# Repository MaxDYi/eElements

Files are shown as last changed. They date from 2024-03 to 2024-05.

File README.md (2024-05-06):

# 墨水屏元素周期表

# 0 目录

1. 简介
2. 原理图
3. PCB
4. 外壳
5. 物料清单
6. 成本核算
7. 代码实现
8. 功耗分析

# 1 简介

电子沙漏使用STM32L431CCT6作为主控，驱动1.54寸墨水屏（200x200分辨率），待机功耗低。

- 原子序数、原子序数、相对原子量、核外电子排布以及中英文原子名称。
- 整机刷新功耗5mA，休眠功耗136uA，续航达数月。

# 2 原理图

eElements-SCH_page-0001

# 3 PCB





PCB使用4层板设计，面积3.2x4.0cm，全部元器件均位于背面。

# 4 外壳

外壳设计详见github库中的**4.Component**部分，共设计**内层**与**外层**两部分，使用3D打印进行实现。

| 元件 | 尺寸 |  体积 |  表面积  |
| :--: | :---: | :-----: | :---: |
| 内层 | 1.17 * 3.2 * 4.24cm | 2.49cm³ | 39.59cm² |
| 外层 | 1.37 * 3.5 * 4.34cm | 3.57cm³ | 73.94cm² |

# 5 物料清单

| Comment | Description | Designator | Footprint | Quantity |
| --- | --- | --- | --- | --- |
| 100nF | 贴片电容/MLCC电容 | C2, C4, C5, C6, C7,  C8, C21, C22, C26, C27 | C0402_M | 10 |
| 1uF/50V | 贴片电容/MLCC电容 | C9, C10, C11, C12,  C13, C14, C15, C16, C17, C18 | C0402_M | 10 |
| 10uF | 贴片电容/MLCC电容 | C19, C20 | C0402_M | 2 |
| 1uF | 贴片电容/MLCC电容 | C23, C24 | C0402_M | 2 |
| 22nF | 贴片电容/MLCC电容 | C25 | C0402_M | 1 |
| 1N5819WS | 肖特基二极管 | D1, D2, D3, D4, D5,  D6, D7 | SOD-323 | 7 |
| DEBUG PAD | 调试断点焊盘 | DE1 | DEBUG_B | 1 |
| TP4056 | 锂电池充电管理 | IC1 | SOIC-8_EP | 1 |
| CON-24P | 2.54寸墨水屏24P连接器 | JP1 | FPC0.5-WT-24P-上接 | 1 |
| HDR-1X2 | 2P连接器 | JP2 | MX1.25-W-2P | 1 |
| HDR-1X4 | 4P连接器 | JP3 | HDR1.27-LI-4P | 1 |
| 47uH/1A | 贴片小功率电感 | L1 | SWPA4030 | 1 |
| GREEN | 贴片LED | LED1, LED3 | LED0603_R | 2 |
| RED | 贴片LED | LED2 | LED0603_R | 1 |
| AO3400 | N沟道 30V/4.2A | Q1, Q3 | SOT23-3N | 2 |
| AO3401 | P沟道 30V/4.2A | Q2 | SOT23-3N | 1 |
| 1K | 贴片电阻 | R1, R7, R8 | R0402_M | 3 |
| 100K | 贴片电阻 | R2, R16 | R0402_M | 2 |
| 4.7K | 贴片电阻 | R3, R4 | R0402_M | 2 |
| 1M | 贴片电阻 | R5, R13, R14, R15,  R19 | R0402_M | 5 |
| 2.2R | 贴片电阻 | R6 | R0603_M | 1 |
| 10K | 贴片电阻 | R9, R12, R17, R18 | R0402_M | 4 |
| 5.1K | 贴片电阻 | R10, R11 | R0402_M | 2 |
| 3x6x5 | 微动开关 | SW1 | SW 3*6*4.3-S-W | 1 |
| 3x6x5 | 微动开关 | SW2, SW3 | SW SMD-3*6*2.5 | 2 |
| STM32L431CCT6 | Ultra-low-power with  FPU Arm Cortex-M4 MCU | U1 | LQFP48_M | 1 |
| RT9193-33GB | LDO 3.3V/0.3A | U2 | SOT-23-5 | 1 |
| CH340K | USB转串口芯片, 内置晶振 | U3 | SOP10_M | 1 |
| TYPE-C 2.0  -16P | USB2.0_Type-C_16Pin母座 | USBC1 | USB-C-SMD_16P | 1 |

# 6 成本核算

|  类目  | 型号 | 采购总价 | 采购数量 | 采购单价 | 使用数量 |  小计  |
| :----: | :---: | :---: | :---: | :---: | :---: | :----: |
|  PCB | 四层板1.6mm |  ¥20.00  | 5 | ¥4.0000  | 1 | ¥4.00  |
|  SMT | 经济型 | ¥100.06  | 5 | ¥20.0120 | 1 | ¥20.01 |
| 元器件 | STM32L431CCT6等  |  ¥7.20 | 1 | ¥7.2000  | 1 | ¥7.20  |
|  外壳  | 外壳（白色树脂） |  ¥4.96 | 1 | ¥4.9600  | 1 | ¥4.96  |
| 锂电池 | 500mAh单节锂电池 |  ¥8.20 | 1 | ¥8.2000  | 1 | ¥8.20  |
|  合计  | | | | | | ¥65.92 |

# 7 代码实现

## 7.1 软件环境

IAR 9.30

STM32CubeMX 6.5.0

## 7.2 主要库

使用到的库位于**\eHorglass\Drivers**路径下。

| 库 | 功能 |
| --- | --- |
| battery | 锂电池相关库 |
| bsp | 开发板相关 |
| element | 元素信息存储 |
| epd | 墨水屏驱动库 |
| parameter | 运行参数配置库 |
| PWRSandMove | 电源与低功耗控制砂砾运动控制核心算法 |

# 8 功耗分析

使用Power Profiler Kit II进行功耗分析。



固件采取刷新后休眠30s的运行模式，对功耗进行测量。

| 模式 | 功耗 | 时长 |
| :---: | :---: | :--: |
| 关机功耗 | 30.95uA  |  0s  |
| 刷新功耗 |  5.09mA  |  2s  |
| 休眠功耗 | 136.13uA | 10s  |

ppk-20240401T023107

ppk-20240401T023441

ppk-20240401T044010

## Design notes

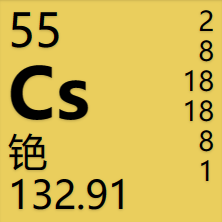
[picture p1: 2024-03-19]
6.Docs/参考排版/元素图例（无边框）.png

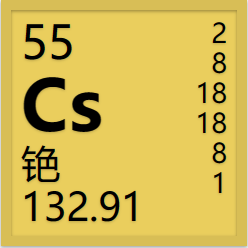
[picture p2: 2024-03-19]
6.Docs/参考排版/元素图例.png

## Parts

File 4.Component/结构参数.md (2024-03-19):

屏幕 37.32x31.8x0.98mm

PCB 40.0x32.0x1.6mm

外壳厚度1.2mm

器件高度4.0mm

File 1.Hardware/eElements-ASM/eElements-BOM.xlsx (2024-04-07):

Comment | Description | Designator | Footprint | LibRef | Quantity
100nF | 贴片电容/MLCC电容 | C2, C4, C5, C6, C7, C8, C21, C22, C26, C27 | C0402_M | C | 10
1uF/50V | 贴片电容/MLCC电容 | C9, C10, C11, C12, C13, C14, C15, C16, C17, C18 | C0402_M | C | 10
10uF | 贴片电容/MLCC电容 | C19, C20 | C0402_M | C | 2
1uF | 贴片电容/MLCC电容 | C23, C24 | C0402_M | C | 2
22nF | 贴片电容/MLCC电容 | C25 | C0402_M | C | 1
1N5819WS | 肖特基二极管 | D1, D2, D3, D4, D5, D6, D7 | SOD-323 | 1N5819 | 7
DEBUG PAD | 调试断点焊盘 | DE1 | DEBUG_B | DEBUG | 1
TP4056 | 锂电池充电管理 | IC1 | SOIC-8_EP | TP4056 | 1
CON-24P | 2.54寸墨水屏24P连接器（上接点或上下接点24PIN的0.5mmFPC插座） | JP1 | FPC0.5-WT-24P-上接 | EPD-1.54 | 1
HDR-1X2 | 2P连接器 | JP2 | MX1.25-W-2P | Header 2 | 1
HDR-1X4 | 4P连接器 | JP3 | HDR1.27-LI-4P | Header 4 | 1
47uH/1A | 贴片小功率电感 | L1 | SWPA4030 | L | 1
GREEN | 贴片LED | LED1, LED3 | LED0603_R | LED | 2
RED | 贴片LED | LED2 | LED0603_R | LED | 1
AO3400 | N沟道 30V/4.2A | Q1, Q3 | SOT23-3N | AO3400 | 2
AO3401 | P沟道 30V/4.2A | Q2 | SOT23-3N | AO3401 | 1
1K | 贴片电阻 | R1, R7, R8 | R0402_M | R | 3
100K | 贴片电阻 | R2, R16 | R0402_M | R | 2
4.7K | 贴片电阻 | R3, R4 | R0402_M | R | 2
1M | 贴片电阻 | R5, R13, R14, R15, R19 | R0402_M | R | 5
2.2R | 贴片电阻 | R6 | R0603_M | R | 1
10K | 贴片电阻 | R9, R12, R17, R18 | R0402_M | R | 4
5.1K | 贴片电阻 | R10, R11 | R0402_M | R | 2
3x6x5 | 微动开关 | SW1 | SW 3*6*4.3-S-W | SW-PB | 1
3x6x5 | 微动开关 | SW2, SW3 | SW SMD-3*6*2.5 | SW-PB | 2
STM32L431CCT6 | Ultra-low-power with FPU Arm Cortex-M4 MCU 80 MHz with 256 Kbytes of Flash memory | U1 | LQFP48_M | STM32L431CCT6 | 1
RT9193-33GB | LDO 3.3V/0.3A | U2 | SOT-23-5 | RT9193-33GB | 1
CH340K | USB转串口芯片, 内置晶振 | U3 | SOP10_M | CH340K | 1
TYPE-C 2.0 -16P | USB2.0_Type-C_16Pin母座 | USBC1 | USB-C-SMD_16P | USB2.0_Type-C_16Pin | 1

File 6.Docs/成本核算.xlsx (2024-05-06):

类目 | 型号 | 采购总价 | 采购数量 | 采购单价 | 使用数量 | 小计
PCB | 四层板1.6mm | ¥20.00 | 5 | ¥4.0000 | 1 | ¥4.00 | ¥4.00
SMT | 经济型 | ¥100.06 | 5 | ¥20.0120 | 1 | ¥20.01 | ¥20.01
元器件 | STM32L431CCT6 | ¥7.20 | 1 | ¥7.2000 | 1 | ¥7.20
 | 墨水屏 | ¥16.50 | 1 | ¥16.5000 | 1 | ¥16.50
 | CH340K | ¥1.90 | 1 | ¥1.9000 | 1 | ¥1.90
 | TP4056X | ¥1.15 | 1 | ¥1.1500 | 1 | ¥1.15
 | 其他 | ¥10.00 | 5 | ¥2.0000 | 1 | ¥2.00 | ¥28.75
外壳 | 内层 | ¥2.04 | 1 | ¥2.0400 | 1 | ¥2.04
 | 外层 | ¥2.92 | 1 | ¥2.9200 | 1 | ¥2.92
锂电池 | 500mAh单节锂电池 | ¥8.20 | 1 | ¥8.2000 | 1 | ¥8.20
合计 |  |  |  |  |  | ¥65.92

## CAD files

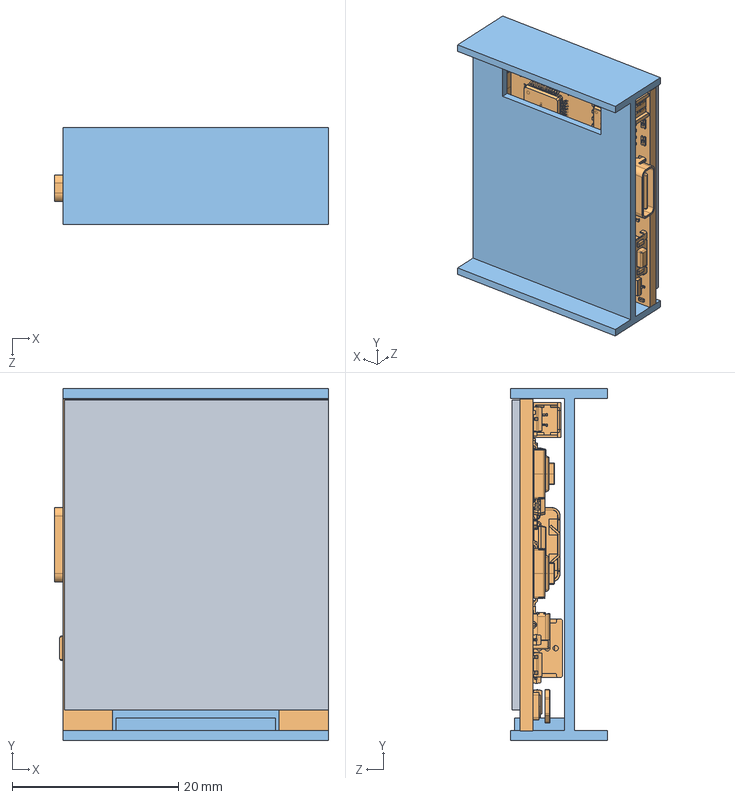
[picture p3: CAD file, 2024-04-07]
4.Component/装配体/内部装配体.SLDASM
33.0 x 42.4 x 11.7 mm
1.54寸电子纸
PCB
内层

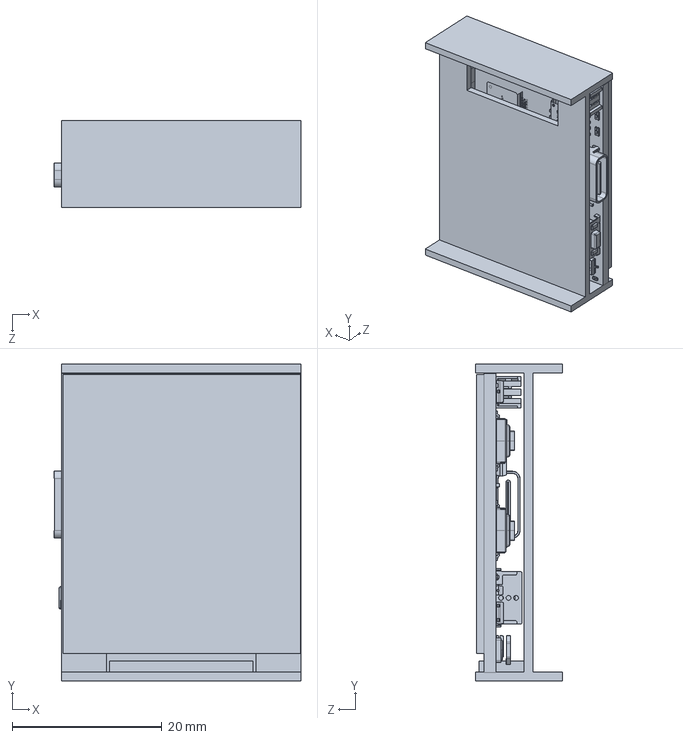
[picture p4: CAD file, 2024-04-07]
4.Component/装配体/整体装配体.SLDASM
33.0 x 42.4 x 11.7 mm

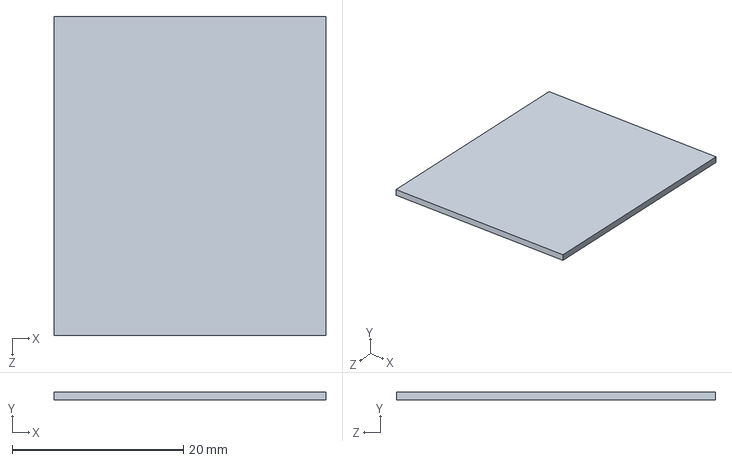
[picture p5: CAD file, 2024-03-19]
4.Component/1.54寸电子纸/1.54寸电子纸.SLDPRT
31.8 x 0.98 x 37.3 mm

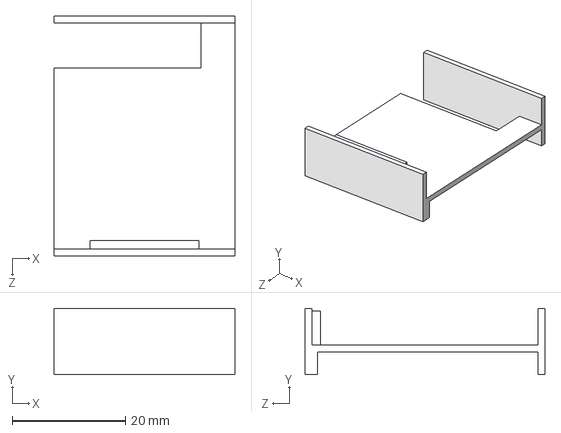
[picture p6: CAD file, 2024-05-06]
4.Component/外壳/内层.STEP
32.0 x 11.7 x 42.4 mm

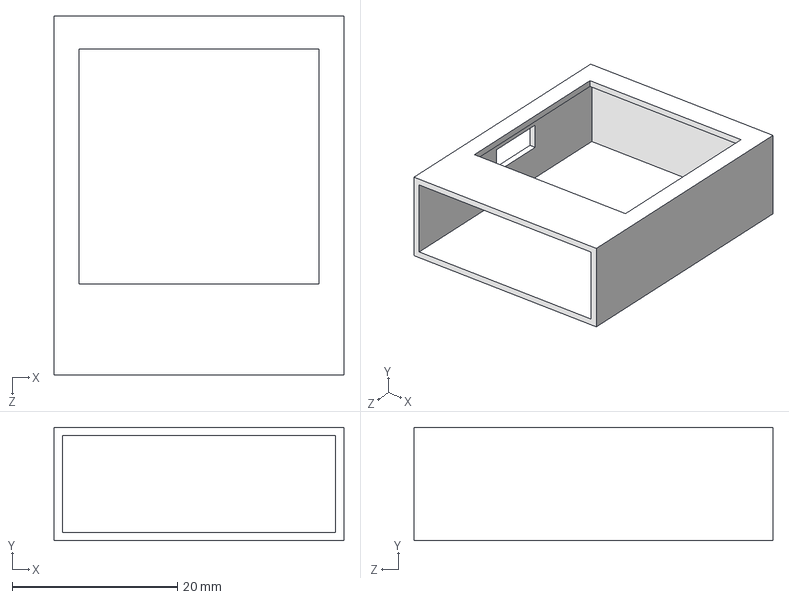
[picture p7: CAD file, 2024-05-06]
4.Component/外壳/外壳.STEP
35.0 x 13.7 x 43.4 mm

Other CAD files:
4.Component/外壳/内层.SLDPRT
4.Component/外壳/外壳.SLDPRT
4.Component/装配体/内部装配体.SLDPRT

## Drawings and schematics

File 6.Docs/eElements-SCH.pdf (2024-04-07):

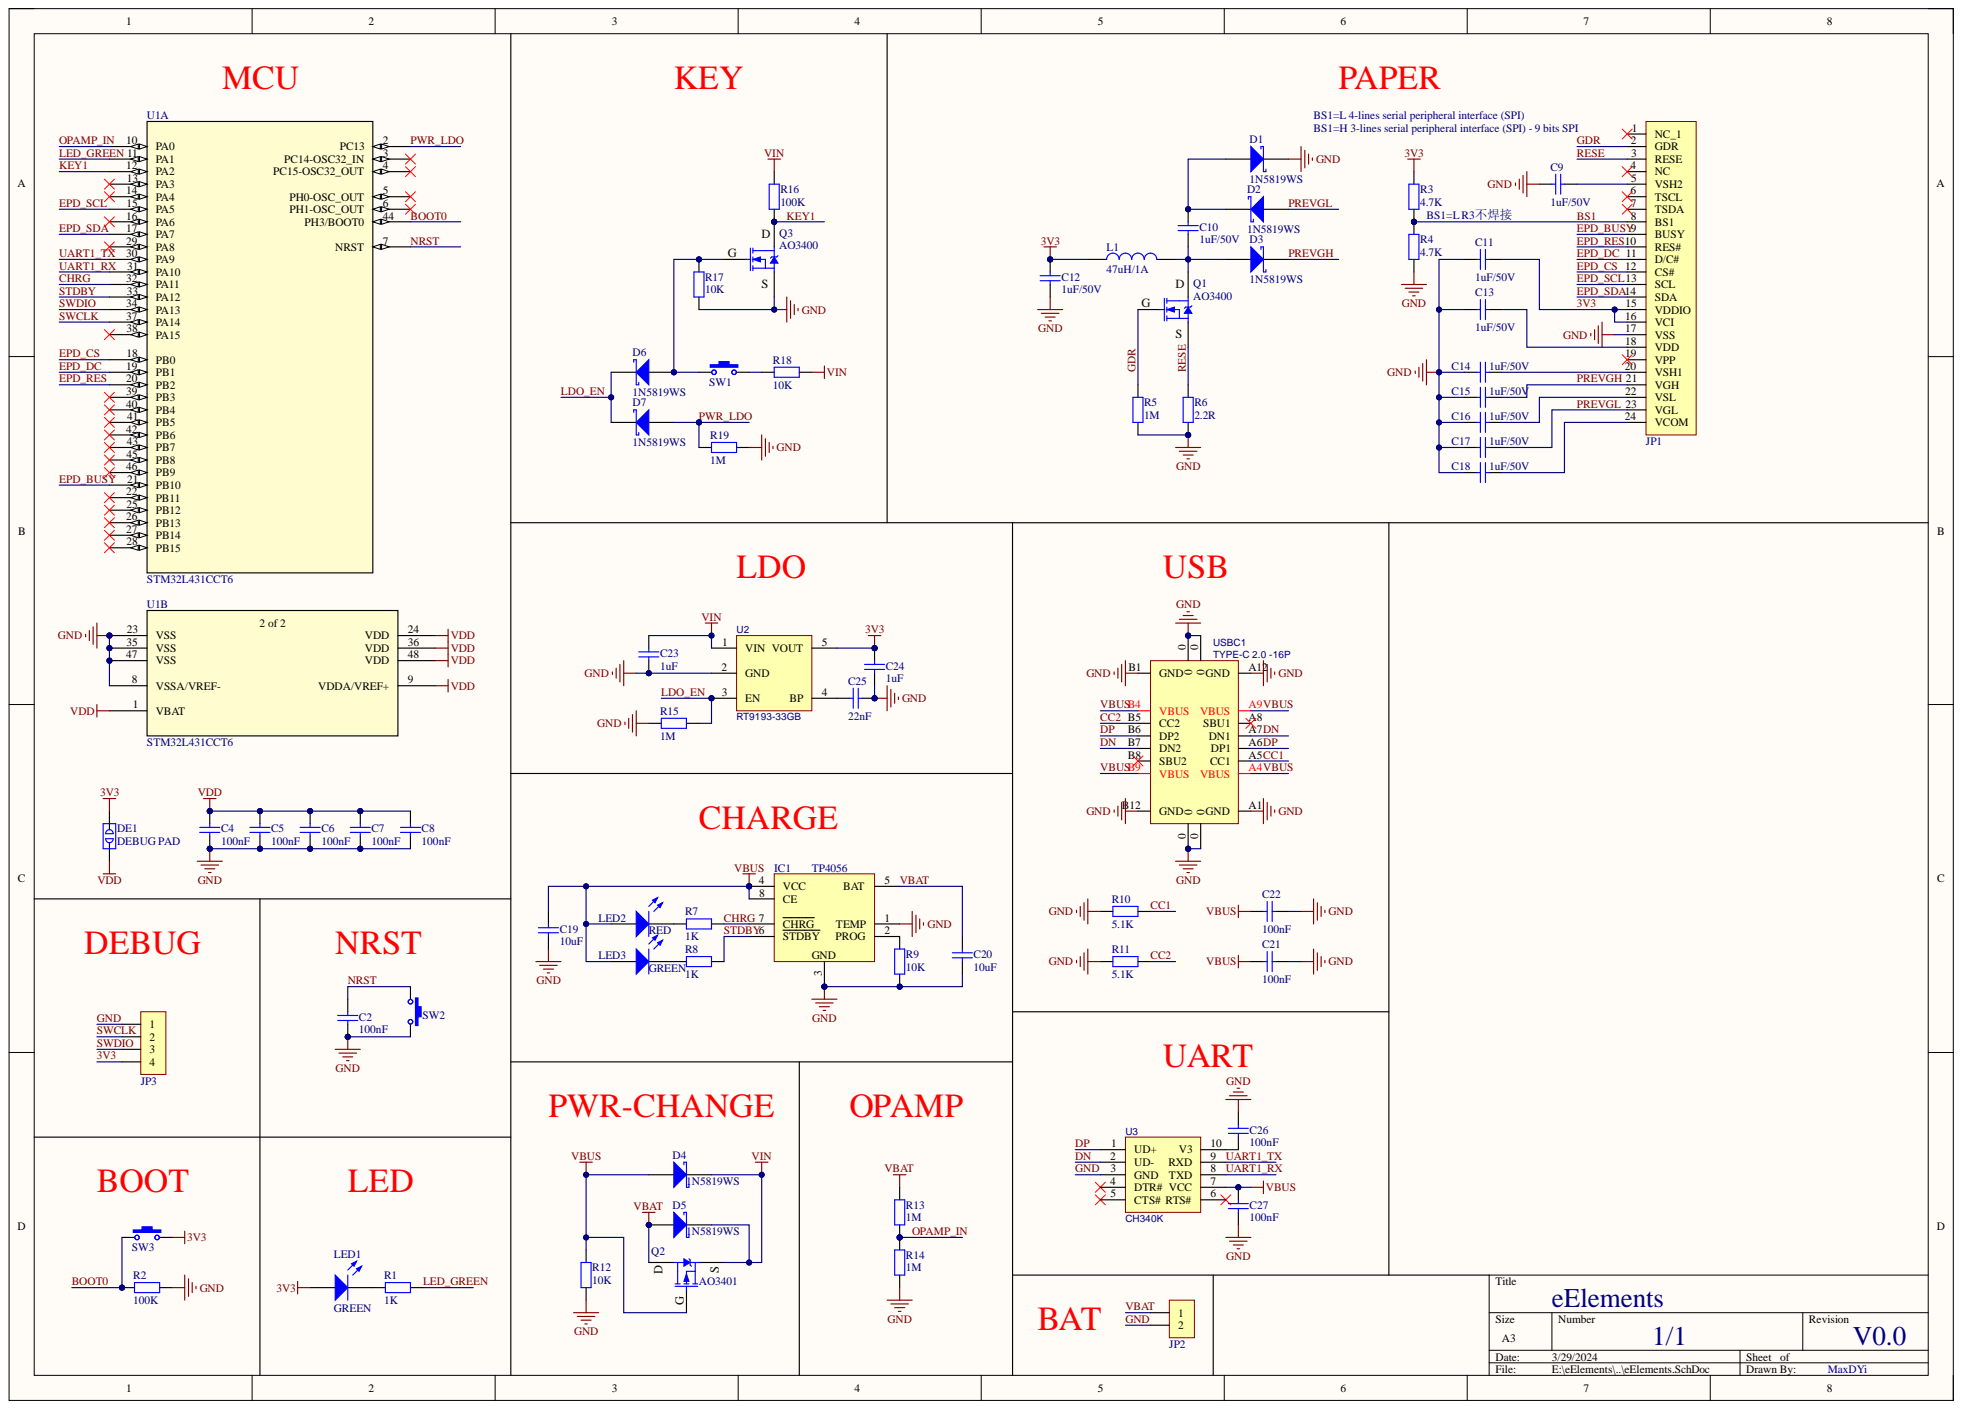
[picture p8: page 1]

BS1=L 4-lines serial peripheral interface (SPI)
BS1=H 3-lines serial peripheral interface (SPI) - 9 bits SPI

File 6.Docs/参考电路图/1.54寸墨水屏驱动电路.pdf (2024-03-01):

接口配置方法： 4线SPI接口焊接：R2 | BS1=L 4-lines serial peripheral interface (SPI)
3线SPI接口焊接：R3 | BS1=H 3-lines serial peripheral interface (SPI) – 9 bits SPI

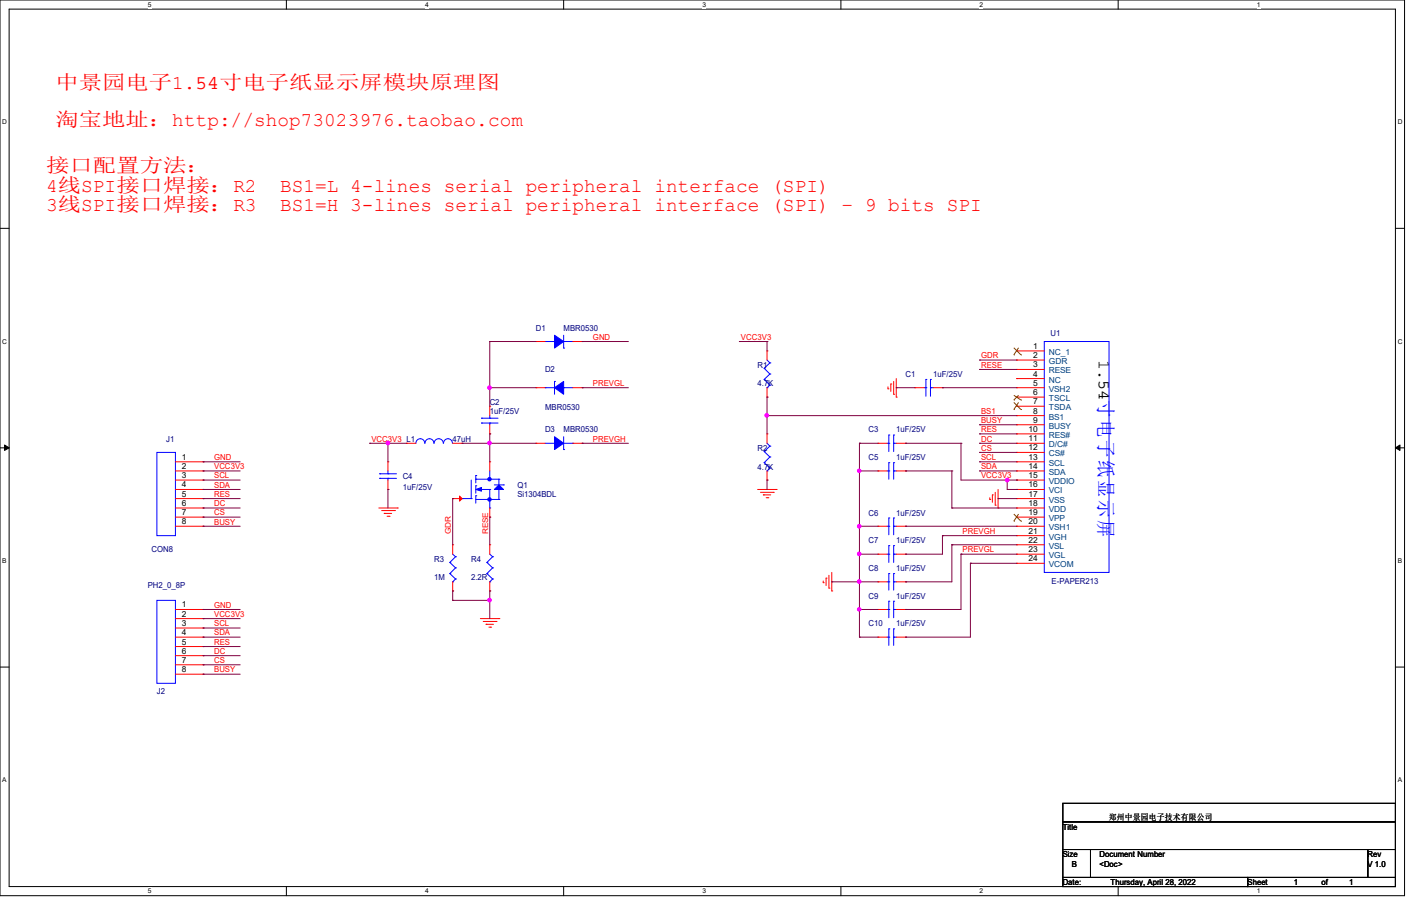
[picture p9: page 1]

淘宝地址：http://shop73023976.taobao.com

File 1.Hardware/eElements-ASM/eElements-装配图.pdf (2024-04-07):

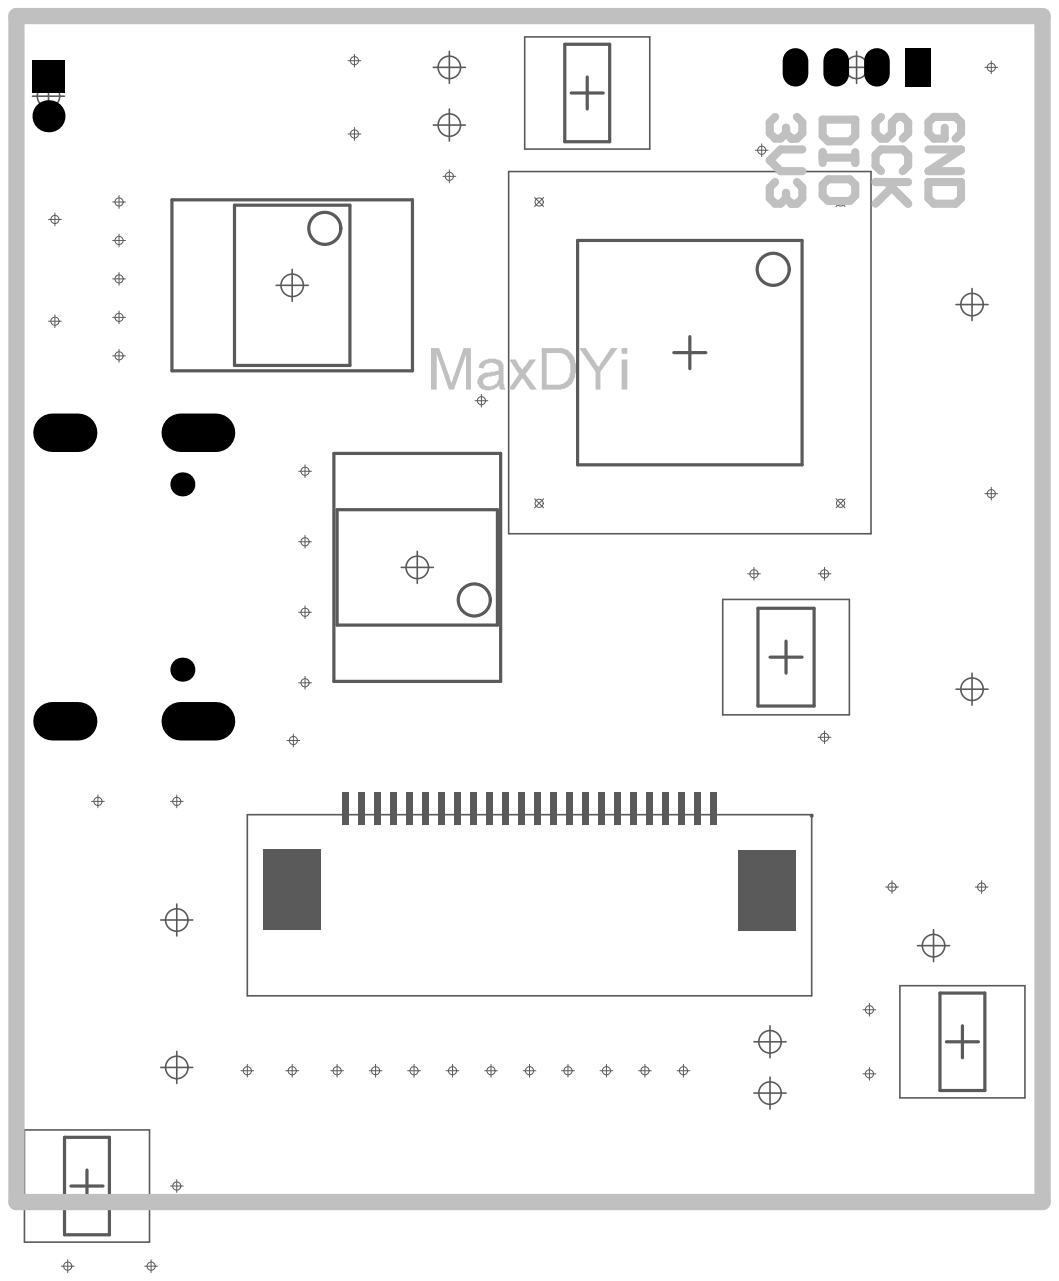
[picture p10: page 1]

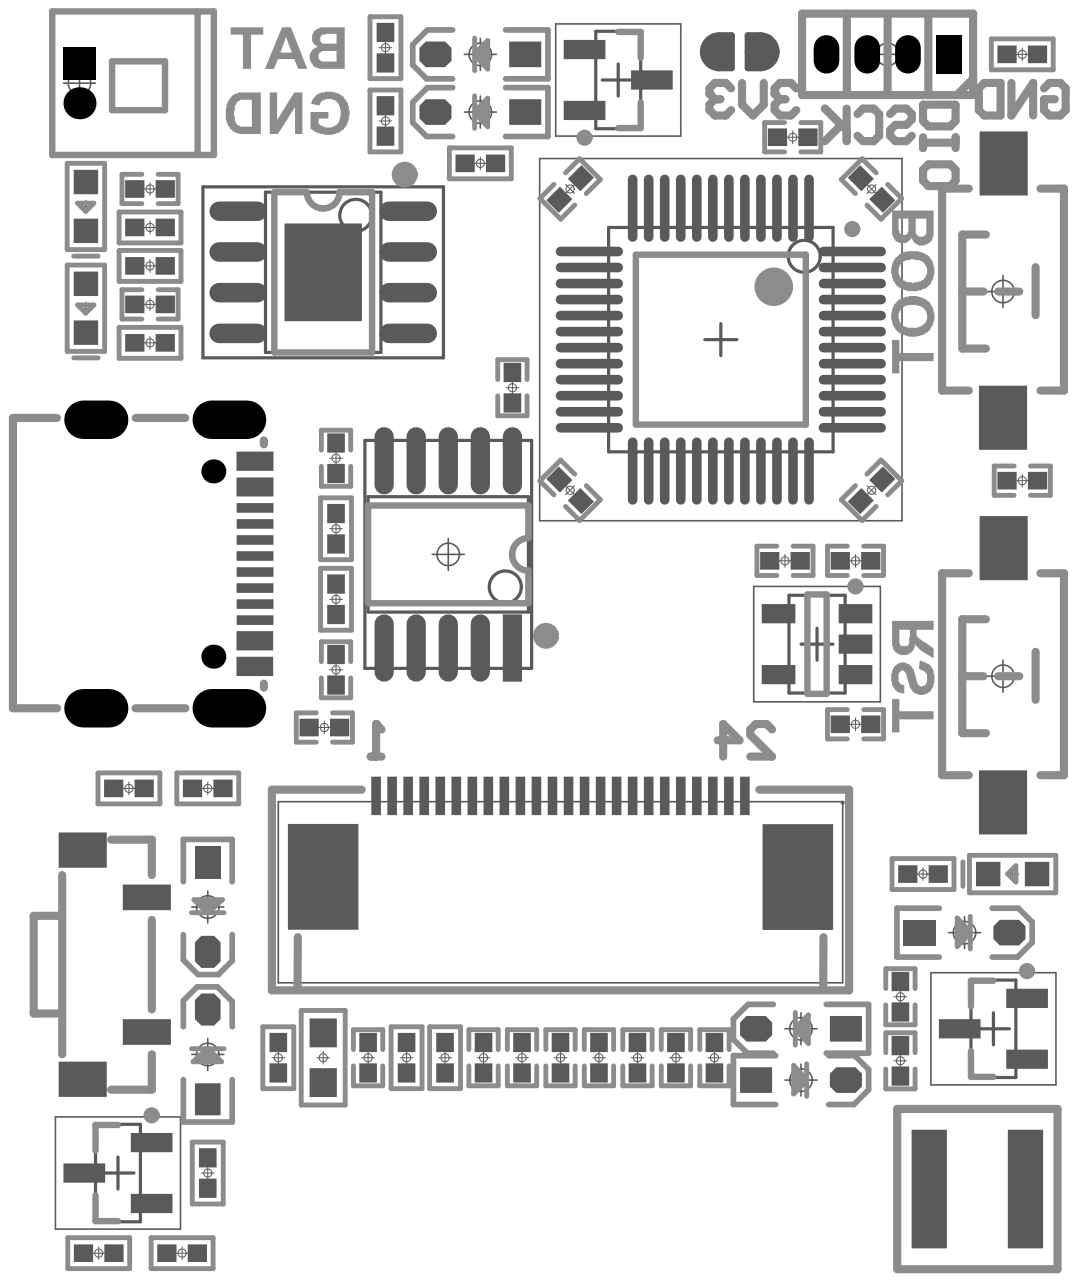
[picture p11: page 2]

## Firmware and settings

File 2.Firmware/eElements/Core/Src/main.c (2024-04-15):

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
/* Includes ------------------------------------------------------------------*/
#include "main.h"
#include "adc.h"
#include "opamp.h"
#include "rtc.h"
#include "spi.h"
#include "usart.h"
#include "gpio.h"

/* USER CODE BEGIN Includes */
#include "stdio.h"
#include "stdlib.h"
#include "string.h"
#include "epd_gui.h"
#include "element.h"
#include "PWR.h"
#include "bsp.h"
#include "battery.h"
#include "parameter.h"
#include "stm32l4xx_hal.h"
/* USER CODE END Includes */


void SystemClock_Config(void);
/* USER CODE BEGIN 0 */
struct parameters runPara;

uint8_t KEY_WKUP = FALSE;

void HAL_GPIO_EXTI_Rising_Callback(uint16_t GPIO_Pin) {
    if (GPIO_Pin == KEY_Pin) {
        KEY_WKUP = TRUE;
    }
}

/* USER CODE END 0 */

/**
  * @brief  The application entry point.
  * @retval int
  */
int main(void)
{
  /* MCU Configuration--------------------------------------------------------*/

  /* Reset of all peripherals, Initializes the Flash interface and the Systick. */
  HAL_Init();

  /* Configure the system clock */
  SystemClock_Config();

  /* Initialize all configured peripherals */
  MX_GPIO_Init();
  MX_SPI1_Init();
  MX_ADC1_Init();
  MX_OPAMP1_Init();
  MX_RTC_Init();
  MX_USART1_UART_Init();
  /* USER CODE BEGIN 2 */
    WKUP_Deinit();
    KEY_GPIO_Init();
    PWR_LDO_GPIO_Init();
    if (KEY_Hold(5) == KEY_DOWN) {
        PWR_LDO_On();
    }
    else {
        PWR_LDO_Off();
    }

    if (PWR_PowerEnough() == FALSE) {
        EPD_DrawLowVoltage();
        PWR_LDO_Off();
    }
    LoadParameters(&runPara);
    uint8_t frameNum = 0;
    uint16_t stopTime = 0;
    uint16_t remainStopTime = 0;
    //uint64_t totalStopTime = 10 * 2000;
    uint64_t totalStopTime = (runPara.sleepTime - 2) * 2000;
    remainStopTime = totalStopTime;

    for (uint8_t i = frameNum;i < ELEMENT_NUM;i++) {
        if (runPara.showFlag[i] == 1) {
            EPD_DrawFrame(i , runPara.showStr);
            frameNum = i + 1;
            break;
        }
    }

  /* USER CODE END 2 */

  /* Infinite loop */
  /* USER CODE BEGIN WHILE */
    while (1)
    {
    /* USER CODE END WHILE */

    /* USER CODE BEGIN 3 */
        if (remainStopTime > 0) {
            if (remainStopTime >= 65535) {
                stopTime = 65535;
                remainStopTime = remainStopTime - 65535;
            }
            else {
                stopTime = remainStopTime;
                remainStopTime = 0;
            }
            PWR_EnterStop2Mode(stopTime);
            PWR_ExitStop2Mode();
            if (KEY_WKUP == TRUE) {
                KEY_WKUP = FALSE;
                remainStopTime = 0;
            }
        }
        else {
            remainStopTime = totalStopTime;
            if (KEY_Hold(5) == KEY_DOWN) {
                EPD_DrawEmpty();
                PWR_LDO_Off();
            }

            if (PWR_PowerEnough() == FALSE) {
                EPD_DrawLowVoltage();
                PWR_LDO_Off();
            }

            if (1) {
                while (1) {
                    if (runPara.showFlag[frameNum] == 1) {
                        EPD_DrawFrame(frameNum , runPara.showStr);
                        frameNum++;
                        break;
                    }
                    else {
                        frameNum++;
                    }
                    if (frameNum >= ELEMENT_NUM) {
                        frameNum = 0;
                    }
                }
            }
            else {

            }
        }
    }
  /* USER CODE END 3 */
}

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


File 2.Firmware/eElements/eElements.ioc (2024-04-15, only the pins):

Mcu.UserName=STM32L431CCTx
PA0.Signal=OPAMP1_VINP
PA1.GPIO_Label=LED_GREEN
PA1.Signal=GPIO_Output
PA10.Signal=USART1_RX
PA11.GPIO_Label=BAT_CHRG
PA11.Signal=GPIO_Input
PA12.GPIO_Label=BAT_STDBY
PA12.Signal=GPIO_Input
PA2.GPIO_Label=KEY
PA2.Signal=GPXTI2
PA3.Signal=OPAMP1_VOUT
PA5.GPIO_Label=EPD_SCL
PA5.Signal=SPI1_SCK
PA7.GPIO_Label=EPD_SDA
PA7.Signal=SPI1_MOSI
PA9.Signal=USART1_TX
PB0.GPIO_Label=EPD_CS
PB0.Signal=SPI1_NSS
PB1.GPIO_Label=EPD_DC
PB1.Signal=GPIO_Output
PB10.GPIO_Label=EPD_BUSY
PB10.Signal=GPIO_Input
PB2.GPIO_Label=EPD_RES
PB2.Signal=GPIO_Output
PC13.GPIO_Label=PWR_LDO
PC13.Signal=GPIO_Output

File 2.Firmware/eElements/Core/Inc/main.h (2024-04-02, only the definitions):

#define PWR_LDO_Pin GPIO_PIN_13
#define PWR_LDO_GPIO_Port GPIOC
#define LED_GREEN_Pin GPIO_PIN_1
#define LED_GREEN_GPIO_Port GPIOA
#define KEY_Pin GPIO_PIN_2
#define KEY_GPIO_Port GPIOA
#define KEY_EXTI_IRQn EXTI2_IRQn
#define EPD_SCL_Pin GPIO_PIN_5
#define EPD_SCL_GPIO_Port GPIOA
#define EPD_SDA_Pin GPIO_PIN_7
#define EPD_SDA_GPIO_Port GPIOA
#define EPD_CS_Pin GPIO_PIN_0
#define EPD_CS_GPIO_Port GPIOB
#define EPD_DC_Pin GPIO_PIN_1
#define EPD_DC_GPIO_Port GPIOB
#define EPD_RES_Pin GPIO_PIN_2
#define EPD_RES_GPIO_Port GPIOB
#define EPD_BUSY_Pin GPIO_PIN_10
#define EPD_BUSY_GPIO_Port GPIOB
#define BAT_CHRG_Pin GPIO_PIN_11
#define BAT_CHRG_GPIO_Port GPIOA
#define BAT_STDBY_Pin GPIO_PIN_12
#define BAT_STDBY_GPIO_Port GPIOA
#define SWDIO_Pin GPIO_PIN_13
#define SWDIO_GPIO_Port GPIOA
#define SWCLK_Pin GPIO_PIN_14
#define SWCLK_GPIO_Port GPIOA

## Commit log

2024-03-01 1.54寸墨水屏驱动电路
2024-03-01 STM32L431用户手册
2024-03-01 墨水屏驱动SSD1681手册
2024-03-01 新建工程
2024-03-03 添加STM32L431用户手册
2024-03-12 实现RTC唤醒
2024-03-12 stm32L4低功耗用户手册
2024-03-12 STM32L431CCT6核心板原理图
2024-03-12 stm32l4编程手册
2024-03-13 新建PCB工程
    [eElements.PrjPcb, eElements.SchDoc]
2024-03-13 RT9193用户手册
2024-03-13 SSD1681用户手册
2024-03-13 相关文档
2024-03-13 AO3400用户手册
2024-03-13 TP4056用户手册
2024-03-13 长按开机电路功耗模拟
2024-03-13 替换NMOS管为BSP030
2024-03-13 CH340用户手册
2024-03-13 初版电路工程
    [eElements.SchDoc]
2024-03-14 完成adc与内部跟随器测试
2024-03-14 使用内部低速RC
2024-03-14 修改初版设计
    [eElements.SchDoc]
2024-03-14 替换部分epd驱动引脚
2024-03-14 3月14日版本
    [eElements.SchDoc]
2024-03-15 V0.0版本四层板工程文件
    [eElements-BOM.xlsx, eElements-坐标文件.csv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]
2024-03-15 1.54寸电子纸3D模型
    [1.54寸电子纸.SLDPRT]
2024-03-15 内层壳设计文件
    [内层.SLDPRT, 内层.STEP]
2024-03-15 结构参数文件
2024-03-15 新建装配体
    [装配体.SLDASM]
2024-03-15 3月15日打板PCB模型文件
2024-03-15 3月15日打板初版电路图
2024-03-15 添加主控信息
2024-03-15 更换驱动电子屏的引脚
    [eElements-BOM.xlsx, eElements-坐标文件.csv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]
2024-03-18 3月18日存档
2024-03-19 添加元素周期表参考排版
2024-03-22 添加电子纸常见问题排查工具
2024-03-22 完成118个元素数据
2024-03-28 按键测试完成
2024-03-29 替换BOOT0下拉电阻R2为100K欧
    [eElements-BOM.xlsx, eElements.SchDoc]
2024-03-29 stop2模式功耗910uA
    [eElements-BOM.xlsx, eElements.PrjPcb, eElements.SchDoc]
2024-03-29 2002版LCD取模工具
2024-04-01 stop2模式功耗135uA
2024-04-02 按键唤醒成功
2024-04-02 2002、2018、2021版取模工具
2024-04-02 写入全部汉字字符
    [eElements.SchDoc]
2024-04-07 外移按键
    [Fabrication Testpoint Report for eElements.csv, eElements-BOM.xlsx, eElements-坐标文件.csv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]
2024-04-07 第一版外壳设计
    [内层.SLDPRT, 内层.STEP, 内部装配体.SLDASM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]
2024-04-08 修复RTC唤醒时间错误的问题
2024-04-15 删除未使用字库
2024-04-30 v0.0版本固件
2024-05-06 外壳树脂版打样验证
    [内层.SLDPRT, 内层.STEP, 外壳.SLDPRT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]
2024-05-06 添加功耗分析
2024-05-06 添加成本核算
    [成本核算.xlsx]
2024-05-06 README添加初版描述

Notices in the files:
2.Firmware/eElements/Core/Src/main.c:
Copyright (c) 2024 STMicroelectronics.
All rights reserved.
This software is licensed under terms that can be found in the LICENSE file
